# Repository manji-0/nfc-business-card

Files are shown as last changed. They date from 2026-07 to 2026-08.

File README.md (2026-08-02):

# NFC Business Card (KiCad → JLCPCB)

Passive NFC PCB business card: **89 × 51 mm**, URL NDEF, rewritable from iPhone.

| Item | Value |
|---|---|
| IC | NXP **NT3H2111W0FHKH** (Type 2 / NTAG I²C plus) |
| LCSC | **C710403** (JLCPCB Extended, SMT) |
| Board | 2-layer, **0.8 mm**, **black** mask, white silk, ENIG |
| Antenna | Right zone ~29 × 45 mm, **5 turns**, 0.25 / 0.30 mm |
| Text zone | Left **50 mm** — name as **ENIG copper**; roles / QR / contacts in silk |
| Components | 7 mm strip between text and antenna (U1 + C1 DNP) |

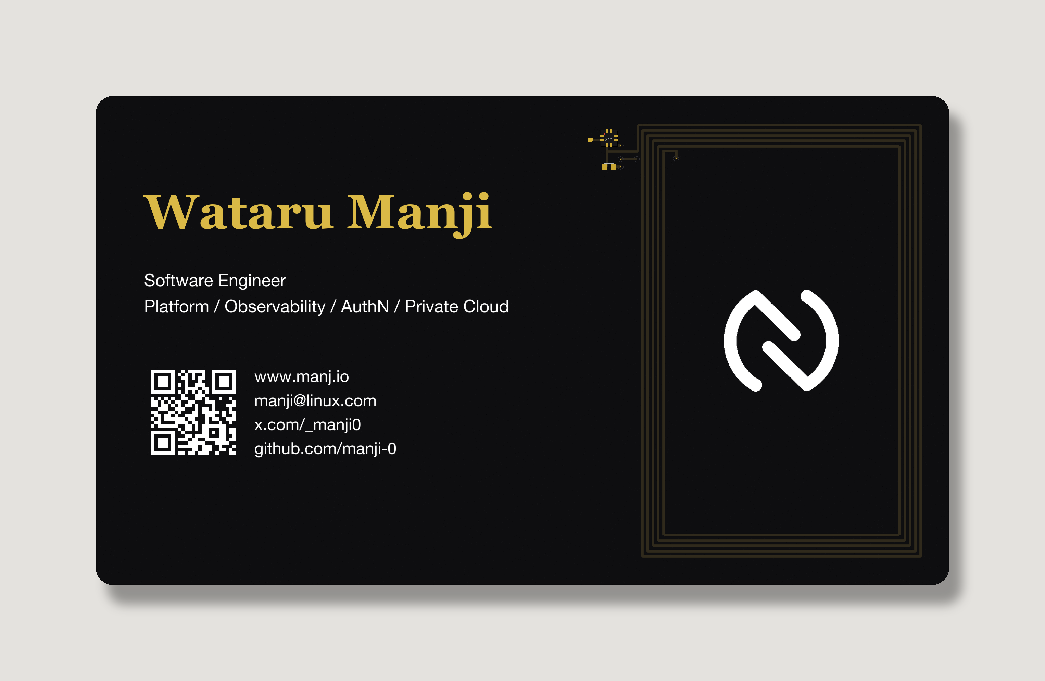
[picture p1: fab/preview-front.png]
Front preview — photoreal mockup


## Repo layout

```
nfc-business-card.kicad_*   KiCad project
lib/                        Symbols & footprints
antenna/                    Design notes + spiral points
fab/                        Gerber zip, BOM, CPL, preview, gerber/
scripts/                    Regenerate project / fab
parts.md                    Locked BOM
```

## Setup (from scratch)

Use **[devbox](https://www.jetify.com/devbox)** + **[uv](https://docs.astral.sh/uv/)** for Python and tooling. KiCad 10+ is installed separately.

```bash
git clone https://github.com/manji-0/nfc-business-card.git
cd nfc-business-card
devbox shell          # installs python, uv, rsvg-convert; runs uv sync
./task export
```

Full guide: **[SETUP.md](SETUP.md)** (fonts, KiCad path, troubleshooting).

## Regenerate design

```bash
./task export          # full pipeline: assets → KiCad → preview → check → fab
./task design          # design only (no Gerber export)
./task list            # show all tasks
```

Individual steps: `./task assets project preview fab` (runs in order).

Open `nfc-business-card.kicad_pro` in KiCad 8+ to edit silk text, tweak antenna, or re-export with **JLCPCB Fabrication Toolkit**.

Photoreal mockup (front + back, regenerated by `./task preview`):

```bash
./task preview
```

Front NFC icon: `assets/nfc-symbol.svg` (from SVG Repo). Check license/terms if you ship commercially.

## Order on JLCPCB

Follow [`fab/ORDER_CHECKLIST.md`](fab/ORDER_CHECKLIST.md).

1. Upload `fab/nfc-business-card-gerbers.zip` (or KiCad Toolkit output).
2. Enable SMT Assembly; upload `fab/bom.csv` + `fab/positions.csv`.
3. Confirm U1 = C710403 and rotation in the preview.
4. First run: **5 boards**.

## Write / rewrite URL (iPhone & Android)

1. Install **NFC Tools** (or NXP TagWriter).
2. Write → Add record → **URL / URI** → your `https://…` page → Write.
3. Tap the card (iPhone: near the top/camera area on modern models).

### Rules for rewritability

- **Do not** use “Lock”, “Make read-only”, or OTP lock. That is permanent.
- Optional: enable **write password only** (PROT = write protect). Reads still open the URL; rewriting needs the password in the same app session.
- After a successful write, lock the phone and tap again to confirm Safari/Chrome opens without an app.

## Design notes

See [`antenna/NOTES.md`](antenna/NOTES.md) and [`parts.md`](parts.md).

- Left **text zone**: name on **F.Cu** (mask opening + ENIG); roles, QR, contacts in silk.
- NFC antenna + chip sit on the **right** (reference-card style).
- If read range is weak, try C1 ≈ **10 pF NP0** first (LCSC **C301961**); then 12/15/18 pF per `parts.md`.

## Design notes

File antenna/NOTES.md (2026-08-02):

# NFC antenna design notes

Board outline: **89.0 × 51.0 mm** (Edge.Cuts).
Chip: **NT3H2111W0FHKH**, Cin = **50 pF** (datasheet).

## Target inductance

Resonance: \( f = 1 / (2\pi\sqrt{L C}) \)

With \( f = 13.56\,\mathrm{MHz} \), \( C = 50\,\mathrm{pF} \):

\[
L = \frac{1}{(2\pi f)^2 C} \approx 2.76\,\mu\mathrm{H}
\]

Design target: **L ≈ 2.0–2.4 µH** (5 turns). With Cin=50 pF alone this is often **~15–16 MHz**;
parasitics and a DNP C1 (**10–22 pF** NP0) pull toward 13.56 MHz on first article.
If range is still poor after C1, consider 6 turns (L≈2.6 µH).

References:

- NXP AN11276 — NFC antenna design
- NXP AN11786 — Antenna design guide for NTAG I²C
- NT3H2111_2211 product data sheet (50 pF input capacitance)

## Geometry used on this card

| Parameter | Value |
|---|---|
| Text zone (left) | **50 mm** — artwork copper-free except ENIG name |
| Component strip | **7 mm** — U1 + C1 at antenna feed |
| Antenna (right) | **~29.5 × 46 mm**, **5 turns**, 0.25 / 0.30 mm |
| Feed | U1/C1 at spiral left edge; LA/LB buses 0.40 mm pitch, 0.18 mm traces |
| Copper under coil | **None** |

Reference-style segregation: electronics at the feed gap, artwork freedom on the left.

Rough L ≈ **1.9 µH** → f_res ≈ **16 MHz** with Cin=50 pF alone. First-article phone tests + C1 decide trim.

## Layout rules

1. Keep ≥ 3 mm clearance from Edge.Cuts to outer turn.
2. Do not place ground **pour** under the spiral. A single thin B.Cu underpass for LB
   (inner end → component strip) is required so F.Cu feed does not cross the outer turn;
   keep it ≤ feed trace width and well clear of any GND island.
3. Place U1 and C1 pads at the feed gap; short LA/LB traces.
4. VSS has a tiny local copper island left of U1 in the component strip — do not flood the antenna area.
5. Center EP of XQFN-8: **no solder paste / no net** (datasheet).
6. The spiral is **netted F.Cu tracks (net LA)**; the antenna footprint is only a
   **net-tie junction** at the coil inner end (`net_tie_pad_groups "1,2"`). The physical
   bridge copper lives in the footprint as two overlapping connect pads: pad 1 (LA)
   spans from the coil end to the take-off, pad 2 (LB) runs from the take-off down to
   via_in. Overlapping pads in a tie group are exempt from the DRC short test, so the
   coil closes to LB with real copper but no cross-net track touch. Do **not** use a
   track to bridge the pads (KiCad 10 DRC reports an LA/LB short) and do not put the
   pads far apart with no overlap (the board stays open). No un-netted copper may
   exist — un-netted spiral `fp_line` copper makes DRC shorting results **UUID-dependent**
   (0/1/2 errors across regenerations). Keep every copper item netted.

## Verification after PCBA

1. Write a short HTTPS URL with NFC Tools.
2. Tap with iPhone (rear camera area) and Android.
3. Note max reliable distance.
4. If < ~5 mm and flaky, try C1 = 10 pF; iterate ±5 pF.

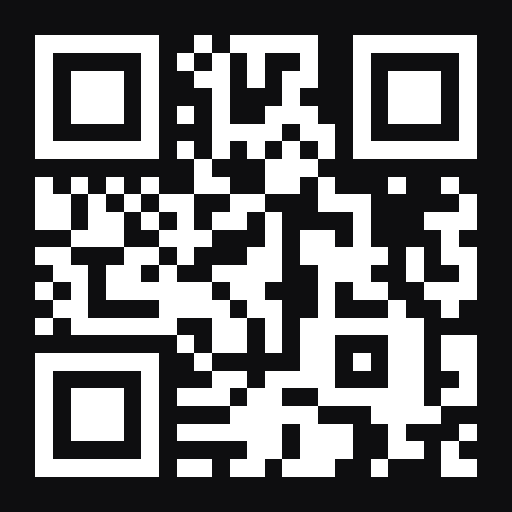
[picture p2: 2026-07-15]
assets/qr-preview.png

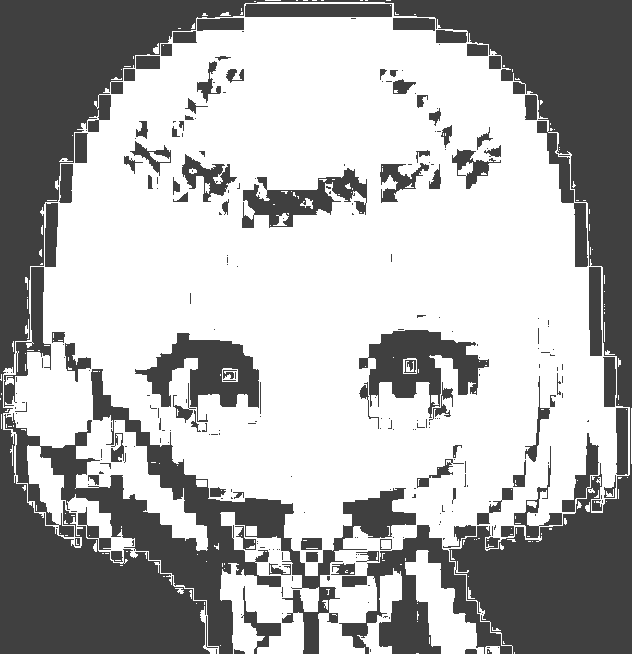
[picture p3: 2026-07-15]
assets/profile-silk.png

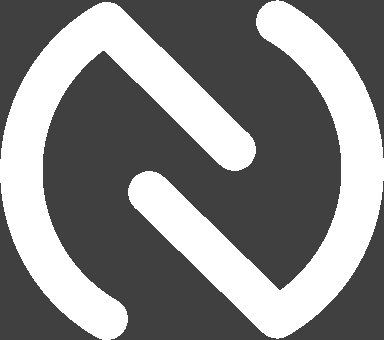
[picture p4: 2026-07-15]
assets/nfc-n-mark-silk.png

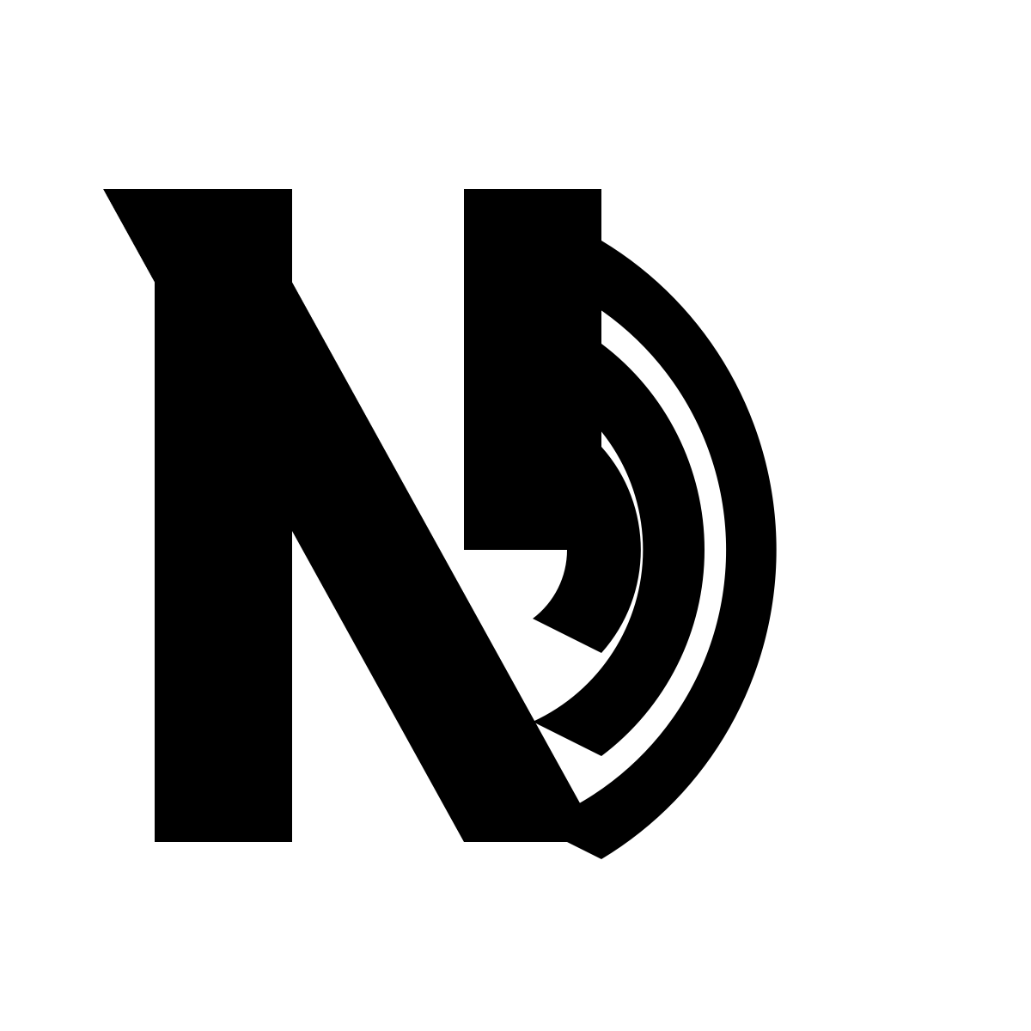
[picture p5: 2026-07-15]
assets/nfc-n-mark.png

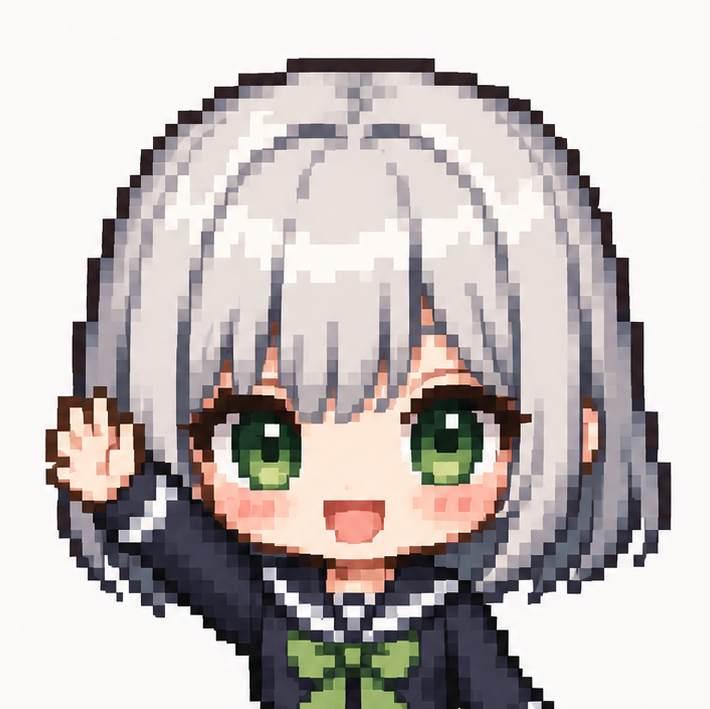
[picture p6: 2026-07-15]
assets/profile.png

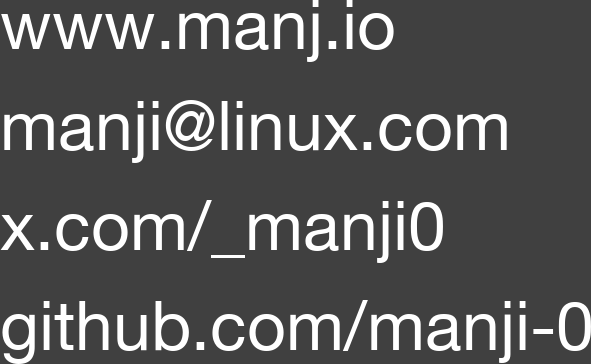
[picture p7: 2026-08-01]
assets/contacts-silk.png

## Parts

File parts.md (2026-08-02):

# Locked BOM — NFC Business Card

Verified 2026-07-14 against LCSC / JLCPCB Parts Library.

## NFC IC (required)

| Field | Value |
|---|---|
| MFR | NXP |
| MPN | **NT3H2111W0FHKH** |
| LCSC / JLCPCB | **C710403** |
| Package | XQFN-8 (1.6 × 1.6 mm), SOT902-3 |
| Type | NFC Forum **Type 2** Tag (NTAG I²C plus, 1 kB) |
| Cin | 50 pF |
| Assembly | JLCPCB SMT (Extended), Economic & Standard |
| LCSC stock (check) | ~10,000+ at lock time |

### Why this part

- Type 2 NDEF → iPhone background URL open works well
- Rewritable from NFC Tools / Core NFC (do not OTP-lock)
- Real SMT package (not wafer / MOA8)
- In stock and listed for JLCPCB assembly

### Pin use (NFC-only business card)

| Pin | Symbol | Connection |
|-----|---|---|
| 1 | LA | Antenna |
| 2 | VSS | Local GND island left of U1 (component strip only; no copper under antenna) |
| 3 | SCL | NC (test pad optional) |
| 4 | FD | NC (test pad optional) |
| 5 | SDA | NC (test pad optional) |
| 6 | VCC | NC (passive RF-powered) |
| 7 | VOUT | NC |
| 8 | LB | Antenna |
| EP | center | **Do not solder** (per datasheet) |

## Tuning capacitor (DNP — pads only)

| Field | Value |
|---|---|
| Ref | C1 |
| Footprint | C_0402_1005Metric |
| Default | **Do Not Place** |
| Candidate if needed | **10–18 pF** NP0/C0G 0402 only (never X7R). See table below. |
| Notes | Parallel across LA–LB. With L≈1.9 µH, Cin=50 pF alone is ~16 MHz; C1 pulls toward 13.56–14.5 MHz. Populate only after first-article phone tests. Run `scripts/tune_antenna.py` for estimates. |

### C1 LCSC parts (verified 2026-08-02)

NP0/C0G **only** — X7R capacitance drifts with voltage/temperature and will not tune reliably at 13.56 MHz.

| Nominal | LCSC | MPN | f_res est. (5T, +3 pF parasitic) | Role |
|---|---|-----|---|---|
| **10 pF** | **C301961** | Walsin 0402N100J500CT | **14.6 MHz** | **Primary** — AN11276 single-tag band (~14.5 MHz) |
| 12 pF | C106201 | YAGEO CC0402JRNPO9BN120 | 14.4 MHz | First SMT populate alternative |
| 15 pF | C106997 | YAGEO CC0402JRNPO9BN150 | 14.0 MHz | If reads still “high” with 10 pF |
| 18 pF | C106202 | YAGEO CC0402JRNPO9BN180 | 13.7 MHz | Toward ISO 13.56 MHz center |
| 22 pF | C1555 | FH 0402CG220J500NT (C0G) | 13.4 MHz | Only if still undertuned after 18 pF |

**BOM default (when populated):** C301961 (10 pF NP0). **First article:** leave DNP; hand-solder 10 pF if range is short.

> **Obsolete/wrong IDs (do not use):** C158992 (681 Ω resistor), C1525 (100 nF X7R), C1528 (160 pF X7R).

## NC pin terminators (DNP — B.Cu pads only)

| Field | Value |
|---|---|
| Ref | R2–R6 |
| Footprint | R_0402_1005Metric (**B.Cu**) |
| Value | **100 kΩ** → VSS (SCL, SDA, FD, VCC, VOUT) |
| MPN | **RC0402FR-07100KL** (YAGEO) |
| LCSC | **C60491** (100 kΩ 0402 ±1%, 62.5 mW) |
| Verified | 2026-08-02 against JLCPCB / LCSC |
| Default | **Do Not Place** |
| Notes | Weak pull-down defines floating NC pins; no RF tuning impact. Populate if field reliability needs margin. |

> **Obsolete/wrong ID (do not use):** C25744 — Uni-Royal 0402WGF1002TCE is **10 kΩ**, not 100 kΩ.

## Alternates (if C710403 unavailable at order time)

1. **ST25TN01K-AFH5** — LCSC C3303589 — Type 2, UFDFN-5 (low stock historically)
2. **ST25TA02K-DC6C5** — LCSC C2654880 — Type 4, UFDFPN-8 (recheck stock)

Do **not** switch to ST25DV / ISO15693 for this card if iPhone tap-to-Safari is required.

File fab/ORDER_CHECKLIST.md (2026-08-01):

# JLCPCB order checklist

## PCB

- Layers: 2
- Dimensions: 89 × 51 mm
- Thickness: **0.8 mm**
- Surface finish: **ENIG**
- Solder mask: **Black**
- Silkscreen: **White**
- Layout: left text zone (ENIG name on F.Cu), right NFC antenna + chip at feed
- Upload **`fab/nfc-business-card-gerbers.zip`** (generated by `./task export` or `./task fab`)
- ENIG name is on **F.Cu** + **F.Mask** opening (not a separate layer)

## SMT Assembly

- Qty: start with **5**
- Side: Top

### Variant A — C1 DNP (hand-tune after test)

- BOM: `fab/bom.csv` (U1 = C710403)
- CPL: `fab/positions.csv`

### Variant B — C1 populated (10 pF NP0, recommended first tuned build)

- BOM: `fab/bom-c1.csv` (U1 = C710403, **C1 = C301961** Walsin 10 pF NP0)
- CPL: `fab/positions-c1.csv` (U1 + C1, F.Cu top)
- C1 value targets ~14.6 MHz resonance (see `scripts/tune_antenna.py`)

CPL uses KiCad pos export (**Mid Y negative**, matches Gerber top-origin).

## Directory layout

```
fab/
  nfc-business-card-gerbers.zip   ← upload to JLCPCB
  bom.csv / positions.csv         ← C1 DNP assembly
  bom-c1.csv / positions-c1.csv   ← C1 populated assembly
  preview.png / preview-front.png
  gerber/                         ← full KiCad export (reference)
```

## Regenerate fab outputs

```bash
./task fab
# or full pipeline:
./task export
```

Requires KiCad 10+ (`kicad-cli` on PATH or macOS app bundle). See [SETUP.md](../SETUP.md).

## JLCPCB options

- Copper: 1 oz (default)
- Board outline tolerance: **Precision** (±0.1 mm) recommended for card size
- Run online DFM before checkout

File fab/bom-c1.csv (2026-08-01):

Designator | Footprint | Quantity | Value | LCSC Part #
U1 | XQFN-8_1.6x1.6mm_P0.4mm_NT3H2111 | 1 | NT3H2111W0FHKH | C710403
C1 | C_0402_1005Metric | 1 | 10pF NP0 | C301961

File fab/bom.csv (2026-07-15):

Designator | Footprint | Quantity | Value | LCSC Part #
U1 | XQFN-8_1.6x1.6mm_P0.4mm_NT3H2111 | 1 | NT3H2111W0FHKH | C710403

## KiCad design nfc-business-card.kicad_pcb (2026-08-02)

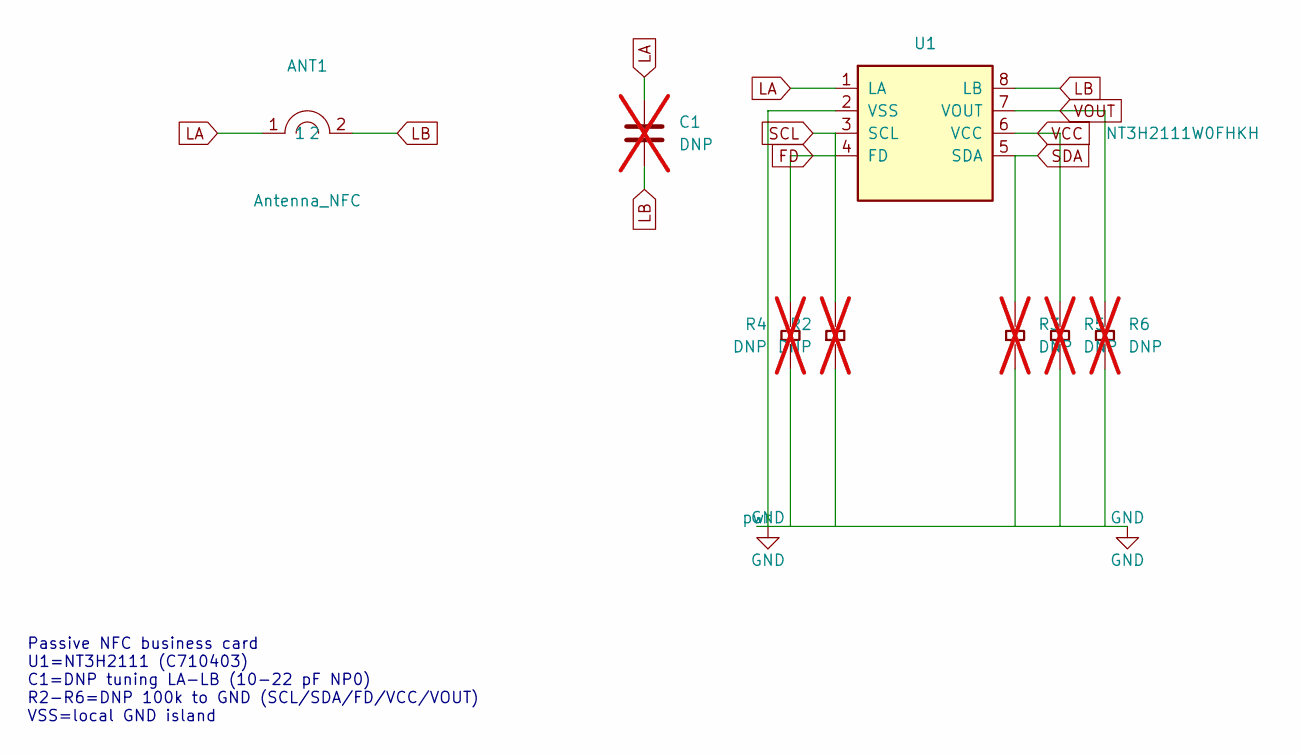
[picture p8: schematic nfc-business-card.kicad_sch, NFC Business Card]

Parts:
ANT1: Antenna_NFC; Antenna_Spiral_29x45_5T
C1: DNP; C_0402_1005Metric; LCSC Part # C301961; not fitted
R2, R3, R4, R5, R6: DNP; R_0402_1005Metric; LCSC Part # C60491; not fitted
U1: NT3H2111W0FHKH; XQFN-8_1.6x1.6mm_P0.4mm_NT3H2111; LCSC Part # C710403

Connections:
FD: R4.1, U1.4 (FD)
GND: R2.2, R3.2, R4.2, R5.2, R6.2, U1.2 (VSS); also elsewhere on the board
LA: ANT1.1, C1.1, U1.1 (LA)
LB: ANT1.2, C1.2, U1.8 (LB)
SCL: R2.1, U1.3 (SCL)
SDA: R3.1, U1.5 (SDA)
VCC: R5.1, U1.6 (VCC)
VOUT: R6.1, U1.7 (VOUT)

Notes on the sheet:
Passive NFC business card U1=NT3H2111 (C710403) C1=DNP tuning LA-LB (10-22 pF NP0) R2-R6=DNP 100k to GND (SCL/SDA/FD/VCC/VOUT) VSS=local GND island

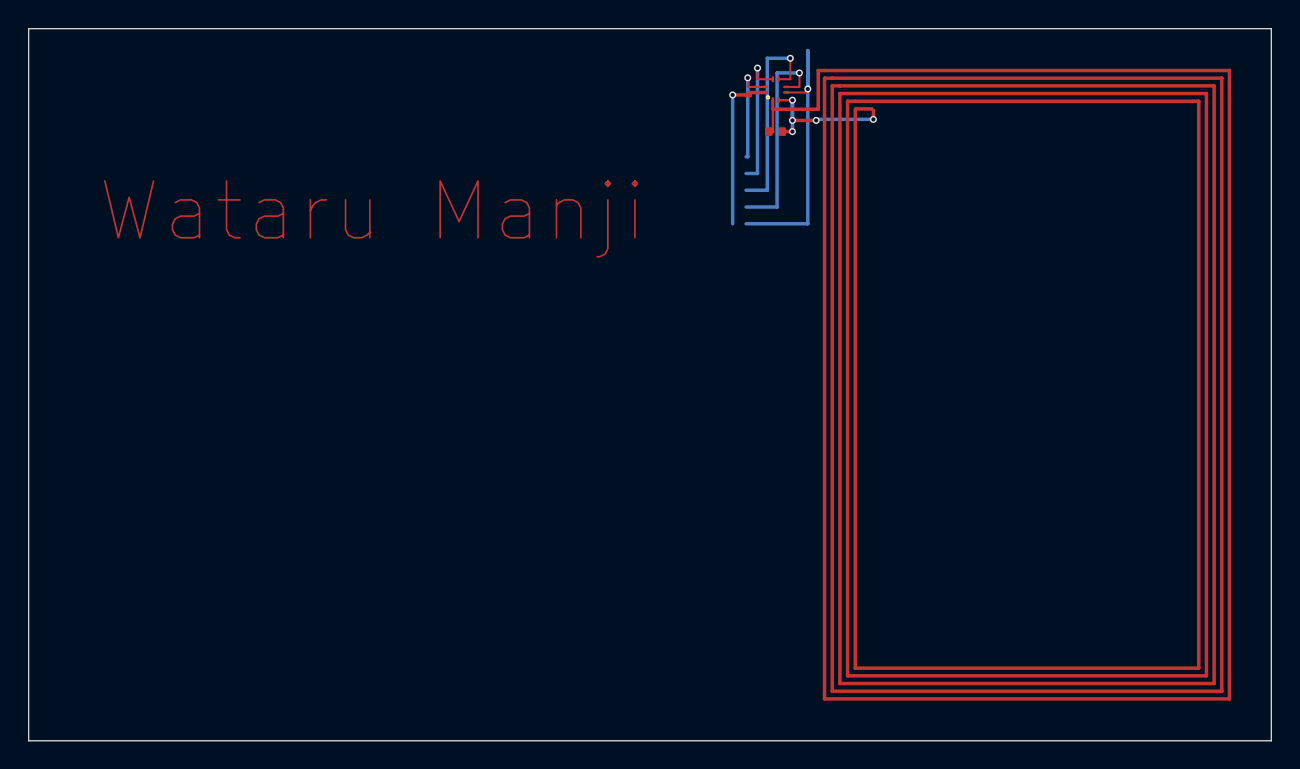
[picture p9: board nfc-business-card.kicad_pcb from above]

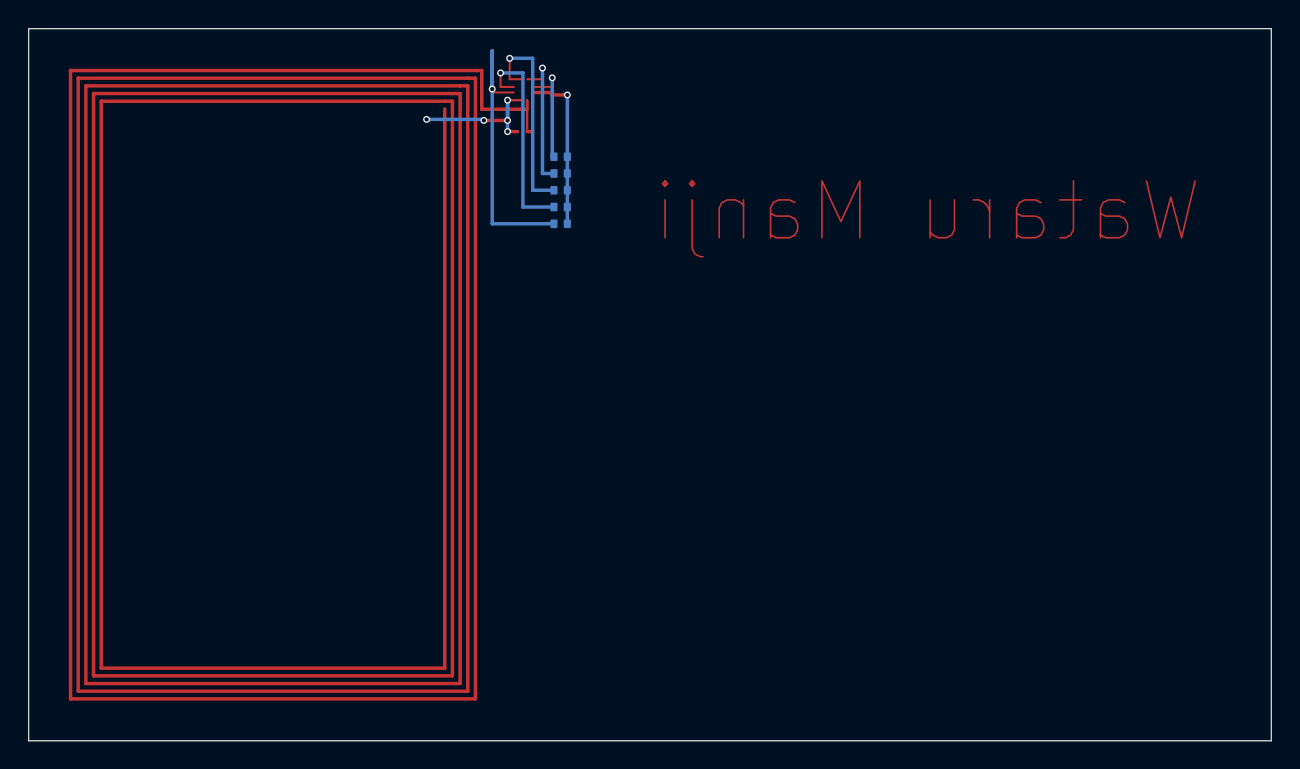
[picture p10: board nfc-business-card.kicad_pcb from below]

Board: 2 copper layers, 89.0 x 51.0 mm, 9 parts (5 on the bottom side), 8 nets.

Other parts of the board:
GND1: GND; GND_Island

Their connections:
GND: GND1.1; also elsewhere on the board

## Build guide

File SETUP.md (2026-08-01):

# セットアップガイド（devbox + uv）

このリポジトリを **1 から** 動かす手順です。Python 依存は **uv**、システムツールは **devbox** で揃えます。KiCad は別途インストールが必要です。

## 前提

| ツール | 用途 |
|---|---|
| [devbox](https://www.jetify.com/devbox) | Python 3.12 / uv / rsvg-convert を隔離インストール |
| [uv](https://docs.astral.sh/uv/) | Python 仮想環境と pip 依存（Pillow, qrcode） |
| **KiCad 10+** | PCB 編集・Gerber 出力・ENIG 名の TTF ベイク |

macOS では KiCad を [公式サイト](https://www.kicad.org/download/) から入れるのが確実です（devbox の `kicad` パッケージは環境によっては入らないことがあります）。

## 1. リポジトリを取得

```bash
git clone https://github.com/manji-0/nfc-business-card.git
cd nfc-business-card
```

## 2. devbox を入れる（未導入の場合）

```bash
curl -fsSL https://get.jetify.com/devbox | bash
```

または [devbox インストール手順](https://www.jetify.com/devbox/docs/installing_devbox/) を参照。

## 3. 開発シェルを起動

```bash
devbox shell
```

初回は Nix パッケージのダウンロードと `uv sync` が走り、`.venv/` が作られます。

シェル内で確認:

```bash
python --version    # 3.12.x
uv --version
rsvg-convert --version
```

## 4. KiCad をインストール

### macOS

1. KiCad 10 を `/Applications/KiCad/` にインストール
2. `devbox shell` / `devbox run` は `scripts/devbox_kicad_path.sh` で App 内 CLI を PATH に載せ、`KICAD_CLI` / `KICAD_PYTHON` / `KICAD_SITE` を自動設定する
3. 確認:

```bash
devbox run -- kicad-cli version
# または
/Applications/KiCad/KiCad.app/Contents/MacOS/kicad-cli version
```

### Linux / カスタムパス

`kicad-cli` が PATH にあるか、環境変数で指定:

```bash
export KICAD_CLI=/path/to/kicad-cli
export KICAD_PYTHON=/path/to/kicad-python   # pcbnew 用（任意）
export KICAD_SITE=/path/to/kicad/site-packages
```

手動で上書きした場合は自動検出より優先される。

## 5. フォント（シルク・ENIG 名）

レイアウトは **Georgia Bold**（氏名）と **Arial**（シルク）を使います。

- **macOS**: システムフォントをそのまま利用（追加不要）
- **Linux**: `fonts-liberation` 等を入れ、必要なら `scripts/layout_metrics.py` / `text_silk.py` のフォントパスを変更

## 6. パイプラインを実行

devbox シェル内:

```bash
./task list
./task design          # アセット → KiCad → プレビュー → チェック
./task export          # 上記 + Gerber zip（KiCad CLI 必須）
```

devbox のショートカット:

```bash
devbox run task
devbox run design
devbox run export
```

## 7. 成果物

| 出力 | パス |
|---|---|
| KiCad プロジェクト | `nfc-business-card.kicad_pro` |
| プレビュー画像 | `fab/preview.png` |
| JLC 用 Gerber zip | `fab/nfc-business-card-gerbers.zip` |
| BOM / CPL | `fab/bom.csv`, `fab/positions.csv` (C1 DNP); **`fab/bom-c1.csv`**, **`fab/positions-c1.csv`** (C1 = C301961 10 pF) |

## トラブルシュート

### `kicad-cli not found`

KiCad をインストールするか `KICAD_CLI` を設定してから `./task fab` を再実行。

### `Georgia Bold` / `Arial` not found

macOS 以外ではフォントパスを確認。`./task design` の前半（PNG 生成）は通っても `generate_kicad_project` の ENIG ベイクで警告が出る場合は KiCad ストロークフォントにフォールバックします。

### `rsvg-convert not found`

`devbox shell` 内で実行しているか確認。devbox の `librsvg` パッケージが `rsvg-convert` を提供します。

### uv / .venv を手動で更新

```bash
uv sync
uv add package-name   # 依存を増やす場合
```

## 最小コマンドまとめ

```bash
git clone https://github.com/manji-0/nfc-business-card.git
cd nfc-business-card
devbox shell
# KiCad 10 をインストール（macOS）
./task export
```

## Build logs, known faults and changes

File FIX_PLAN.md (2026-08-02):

# NFC Business Card PCB Fix Plan

この計画は、短絡、クリアランス違反、部品番号不一致を修正し、修正途中の生成物や未コミット作業を失わないための工程を定義する。

## Verdict

<!-- constrained-by ./AGENTS.md -->

現行出力は発注不可である。2026-08-02 の KiCad 10.0.4 検査では、ERC は通過したが PCB DRC は失敗している。

| 検査 | 現状 | 完了条件 |
|---|---|---|
| KiCad DRC error | 27件 | 0件 |
| KiCad DRC warning | 12件 | 意図したものを除き0件 |
| ERC error | 0件 | 0件 |
| schematic parity | 0件 | 0件 |
| unconnected items | 0件 | 0件 |
| 軽量レイアウト検査 | 通過。ただし不十分 | 強化後も通過 |

## Detected Problems

### Cross-Net Shorting

同一層の異なるネットの配線中心線が交差している。KiCad では `tracks_crossing` として報告されているが、製造上は短絡として扱う。

| ネット | 交差位置 | PCB上の該当配線 |
|---|---|---|
| LA / VOUT | 約 `(54.80, 5.775)` | LA 水平配線と VOUT 垂直配線 |
| GND / VOUT | 約 `(52.25, 4.575)` | GND 水平配線と VOUT 垂直配線 |
| VOUT / GND | 約 `(51.55, 8.90)` | VOUT 水平配線と GND 垂直配線 |

### Clearance

- 要求設計値は 0.20 mm。
- DRCの実測値は 0.025 mm から 0.185 mm。
- 23件すべてが設計値未満。
- 5件は JLC の下限 0.127 mm 未満。
- R3 の SDA パッドと SCL ビアの穴クリアランスは 0.2436 mm で、要求 0.25 mm に届かない。
- LA/LB バスの実効間隔は 0.15 mm で、JLC下限は満たすが設計目標 0.20 mm 未満である。

### Component Identity

<!-- constrained-by ./parts.md -->

- U1 `NT3H2111W0FHKH / C710403` は対象部品と一致する。
- C1 `C301961` は 10 pF、NP0、0402 で対象部品と一致する。
- R2-R6 は設計値が 100 kOhm だが、現在の `C25744` は LCSC上で 10 kOhm 0402 ±1% である。
- R2-R6 はデフォルトDNPのため現行組立BOMには出ないが、オプション実装手順としては不正確である。

## Fixed Design Decisions

<!-- constrained-by ./antenna/NOTES.md -->

- アンテナは 5ターン、トレース 0.25 mm、ターン間ギャップ 0.30 mm、外形約29 x 45 mmを維持する。
- U1 は XQFN-8 1.6 x 1.6 mm、EPは実装しない。
- アンテナ螺旋は net付き F.Cu の LA トラックとし、内側終端は `net_tie_pad_groups "1,2"` の重なりパッドでLBへ接続する。
- no-net の螺旋銅、LA/LBを橋渡しする通常トラック、アンテナ下のGND銅箔は追加しない。
- C1 はDNPを既定とし、初回チューニング用の10 pF NP0候補を維持する。
- R2-R6 はDNPを既定とし、実装する場合だけ検証済み100 kOhm 0402 ±1%部品を指定する。
- `README.md` の6ターン記載は、生成元を変更せず、最後に現行の設計目標へ同期する。

## Worktree Preservation

### Step 0: Freeze the Dirty Worktree

現在の作業ツリーには、PCB、回路図、フットプリント、Gerber、プレビュー、スクリプトの未コミット変更がある。これらを無断で破棄しない。

実施内容:

- `git status --short` を保存する。
- `git diff --stat` と `git diff -- scripts/ nfc-business-card.kicad_pcb nfc-business-card.kicad_pro nfc-business-card.kicad_sch` を確認する。
- 既存変更が今回の修正対象か、別作業かを分類する。
- `.pi/`、一時DRCレポート、実験ファイルを修正対象のコミットから除外する。
- 意図不明の既存変更は、削除・reset・checkoutせず、そのファイルを今回のコミット対象から外す。
- 生成コマンドを実行する前に、上書き対象を確認する。特に `./task design` と `./task export` は生成物を上書きする。

保全ゲート:

- [ ] 既存の変更一覧を作業ログに残した。
- [ ] 今回変更するファイル一覧を確定した。
- [ ] 意図不明の変更をコミットに混ぜない方針を確認した。

コミット:

- 現在の作業ツリーを無断でbaselineコミットしない。
- 既存変更がすべて今回の設計変更であることを確認できた場合だけ、別途 `chore: capture PCB validation baseline` を作成する。

## Validation First

### Step 1: Add Component Invariant Checks

目的は、配線修正と部品修正を同時に行って原因を混ぜないことにある。

変更対象:

- `scripts/check_layout.py` または専用の部品検査スクリプトに、U1、C1、R2-R6のMPN、LCSC ID、値、パッケージ、DNP状態の検査を追加する。
- 100 kOhm指定とLCSC IDの不一致を自動的にエラーにする。
- C1のDNP版と10 pF版がそれぞれ正しいBOM/CPLに出ることを検査する。
- 現行の5ターン、0.25/0.30 mm、3 mmインセットを設計制約として検査する。

検査ゲート:

- [ ] 現行基板で、R2-R6の `C25744` 不一致を再現性のあるエラーとして検出する。
- [ ] U1とC1の正しい部品IDはエラーにならない。
- [ ] 配線問題の失敗と部品問題の失敗を別メッセージで識別できる。

コミット:

- `test: enforce NFC component and antenna invariants`

### Step 2: Add Exhaustive Copper Checks

現行の軽量検査はLA/LBの一部の軸方向重複しか見ておらず、VOUT/GND、VOUT/LAの交差を見逃した。配線修正前に、同じ退行を検出できる検査を先に入れる。

変更対象:

- 同一層の全ネット配線について、交差、重複、最小エッジ間隔を検査する。
- パッド、配線、ビアの銅箔間隔を同一層およびビア貫通範囲で検査する。
- ビア穴とパッド、ビア穴同士のクリアランスを検査する。
- ボード外形、テキストゾーン、アンテナゾーン、コンポーネント帯の境界を検査する。
- net-tie内部のLA/LB重なりだけを明示的な許可リストにする。
- 設計目標 0.20 mm 未満を警告ではなくエラーにする。ただしJLC下限だけを判定する項目は別に残す。
- GNDビアが両層の意図した銅箔へ接続していることを検査する。

検査ゲート:

- [ ] 現行基板で、3箇所の交差を必ず検出する。
- [ ] 0.025 mm、0.095 mm、0.125 mmの既知違反を検出する。
- [ ] 意図したアンテナnet-tieだけは許可される。
- [ ] no-net銅が存在する場合に失敗する。

コミット:

- `test: reject all-net copper crossings and tight clearances`

## Normalize Component Data

### Step 3: Correct the NC Resistor Identity

<!-- constrained-by ./parts.md -->

変更対象:

- `scripts/jlcpcb_limits.py` の `NC_TERM_R_LCSC` を、100 kOhm、0402、±1%として確認したLCSC部品へ変更する。
- `parts.md` のLCSC ID、メーカー型番、抵抗値、定格、検証日を同じ部品に揃える。
- `scripts/generate_kicad_project.py` の生成メタデータは定数から読む状態を維持し、個別のハードコードを増やさない。
- R2-R6のDNP属性、B.Cu配置、SCL/SDA/FD/VCC/VOUTからGNDへの接続意図を維持する。

検査ゲート:

- [ ] 部品検査が通過する。
- [ ] 生成前のソースに100 kOhmとLCSC IDの矛盾がない。
- [ ] 現行PCBをまだ再生成せず、配線修正と混ぜない。

コミット:

- `fix: correct NC terminator component identity`

## Repair Routing in Stages

### Step 4: Build Pure Geometry Routes

<!-- constrained-by ./AGENTS.md -->

配線座標をPCBファイルへ直接編集せず、`scripts/generate_kicad_project.py` の生成元で修正する。

設計手順:

- `nfc_layout()` が返すアンテナ、U1、C1の座標を固定条件として扱う。
- `feed_routes()` のLA/LB RF経路を、既に成立しているアンテナnet-tieとLB B.Cuアンダーパスを壊さない範囲で再配置する。
- `nc_terminator_routes()` の5本のNC経路を、ネットごとの予約チャネルに分ける。
- VOUTの長いF.Cu配線を廃止し、LA、GND、U1パッド、SCLビアを横切らない層遷移を設計する。
- GNDトランクとVOUTトランクは、同一層で交差しないようにする。
- U1直近のF.Cuスタブは、対象パッド以外のU1パッド、他ネットのビア、他ネット配線から0.20 mm以上離す。
- NC信号のB.Cu行配線は、隣接行のパッドとビアを含めて0.20 mm以上離す。
- すべてのNC経路をコンポーネント帯内に収め、アンテナ左辺のkeep-outへ入れない。
- GND遷移は、B.Cuトランクの実配線終端とビア中心を一致させる。未接続の冗長ビアは削除する。

検査ゲート:

- [ ] まず純粋なルートデータを出力し、同一層の全交差が0件である。
- [ ] 全パッド、配線、ビアの最小銅箔間隔が0.20 mm以上である。
- [ ] ビア穴クリアランスが0.25 mm以上である。
- [ ] 既知のLA/VOUT、GND/VOUT、VOUT/GNDの交差が消えている。

コミット:

- `fix: reroute component strip without cross-net tracks`

### Step 5: Pass KiCad DRC on Generated PCB

変更対象:

- `./task design` を実行して、スクリプトからPCB、回路図、フットプリント、プレビューを再生成する。
- `./task check` を実行し、KiCad 10.0.4でERC、DRC、schematic parity、unconnected itemsを検査する。
- DRCのerrorだけでなく、warningを全件確認する。
- `via_dangling`、`lib_footprint_mismatch`、背面フィールドの警告を個別に解消または意図を記録する。

検査ゲート:

- [ ] `./task design` が終了コード0で完了する。
- [ ] DRC errorが0件である。
- [ ] DRC warningが0件、または発注前に許可した理由がある。
- [ ] ERC error、parity、unconnected itemsがすべて0件である。
- [ ] `fab/kicad-drc.json` の生成日時が今回の実行時刻になっている。

コミット:

- 配線修正と同じコミットに生成物を混ぜず、検査が通った後に次の同期コミットへ進む。

## Sync Outputs and Documentation

### Step 6: Synchronize Source and Outputs

<!-- constrained-by ./README.md -->

生成物はソース修正が検査を通った後にだけ更新する。

実施内容:

- `./task design` の出力を確認する。
- `./task fab` を実行し、Gerber、ドリル、BOM、CPL、プレビューを更新する。
- `fab/bom.csv` はC1 DNP版、`fab/bom-c1.csv` はC1 C301961版になっていることを確認する。
- `fab/positions.csv` と `fab/positions-c1.csv` にDNP部品が出ていないことを確認する。
- READMEのアンテナ表記を、生成元と `antenna/NOTES.md` の5ターン、0.25/0.30 mmへ揃える。
- `fab/ORDER_CHECKLIST.md` のU1、C1、基板仕様、検査コマンドを現行出力と照合する。
- transientな `*.rpt`、`fab/kicad-drc.json`、`fab/kicad-erc.json`、`.pi/` はコミット対象にしない。ただし既存の追跡状態を確認してから判断する。

検査ゲート:

- [ ] `git diff --check` が通る。
- [ ] GerberのEdge.Cutsが89 x 51 mmである。
- [ ] 基板厚0.8 mm、2層、黒マスク、白シルク、ENIGの出力条件を確認した。
- [ ] F.Cuアンテナ、B.Cuアンダーパス、GND島、ENIG名の位置をプレビューとGerberで確認した。
- [ ] BOM/CPLの部品IDがソース、PCB、CSVで一致する。

コミット:

- `chore: regenerate verified fabrication outputs`

### Step 7: Independent Pre-Order Review

<!-- constrained-by ./fab/ORDER_CHECKLIST.md -->

生成パイプラインとは別に、発注者が以下を確認する。

- [ ] KiCad DRC画面で除外・無視設定を確認した。
- [ ] 3DまたはGerberビューで、短絡経路がないことを確認した。
- [ ] U1のピン1マークとC1の配置方向を確認した。
- [ ] JLCPCBのオンラインDFMを実行した。
- [ ] U1がC710403、C1 DNP版またはC301961版の選択が正しい。
- [ ] R2-R6を注文BOMへ誤って追加していない。

コミット:

- レポートのみの場合はコミットしない。
- 追加修正が出た場合は、該当するStepへ戻り、新しい修正コミットを作成する。

## Commit Policy

各コミットは1つの責務だけを持たせる。生成物の更新を先行させない。

| 順序 | コミット | 主なファイル | 必須ゲート |
|---|---|---|---|
| 1 | `docs: add staged PCB fix plan` | `FIX_PLAN.md` | Markdown構文、依存関係確認 |
| 2 | `test: enforce NFC component and antenna invariants` | 検査スクリプト | 部品・アンテナ制約を検出 |
| 3 | `test: reject all-net copper crossings and tight clearances` | 検査スクリプト | 現行既知違反を検出 |
| 4 | `fix: correct NC terminator component identity` | `parts.md`, `scripts/jlcpcb_limits.py` | 部品検査通過 |
| 5 | `fix: reroute component strip without cross-net tracks` | `scripts/generate_kicad_project.py` | 交差・クリアランス検査通過 |
| 6 | `chore: regenerate verified fabrication outputs` | PCB、回路図、フットプリント、fab成果物 | `./task check`、BOM/CPL照合 |
| 7 | 必要時のみ追加修正 | 最小範囲 | Step 4以降の該当ゲート |

コミット前に必ず以下を実行する。

- `git status --short`
- `git diff --check`
- `git diff --stat`
- ステージしたファイルだけを対象にした `git diff --cached --check`
- コミットメッセージと変更責務の一致確認

禁止事項:

- `git reset --hard`、`git checkout --`、force pushを使わない。
- 未確認の既存変更を削除しない。
- PCBをKiCad上で直接編集して生成元へ反映しない。
- DRC違反を除外設定で隠して合格扱いにしない。
- 生成されたPCBだけを修正し、次回生成で消える変更を残さない。

## Recovery Procedure

各ステップでゲートが失敗した場合は、次のステップへ進まない。

- 失敗したコマンド、生成日時、エラー件数、座標を記録する。
- 直前のコミットと現在の差分を比較する。
- 修正対象を1つの責務に限定する。
- 生成物を手編集せず、生成元を修正して再生成する。
- 既知の違反件数が増えた場合は、原因を切り分けるまでコミットしない。
- 既にコミット済みのステップへ戻す場合はrevertを新しいコミットとして行い、履歴を書き換えない。

## Summary

<!-- derived-from #verdict -->
<!-- derived-from #detected-problems -->
<!-- derived-from #validation-first -->
<!-- derived-from #normalize-component-data -->
<!-- derived-from #repair-routing-in-stages -->
<!-- derived-from #sync-outputs-and-documentation -->

最初に検査を強化し、次に部品情報を正規化し、その後に生成元の配線を直す。最後にKiCadとfab成果物を再生成して独立レビューを通す。この順序により、配線を直している間に部品IDや生成物の古さが混ざることを防ぐ。

## Conclusion

<!-- derived-from #summary -->

この計画の完了条件は、ソース生成、全ネット銅箔検査、KiCad DRC/ERC、BOM/CPL、Gerber、発注チェックリストが同じ部品仕様と座標制約を示すことである。全ゲートが通るまで発注用zipを更新済みとは扱わない。

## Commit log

2026-07-15 Add NFC business card KiCad generator and layout pipeline.
    Unified preview/KiCad silk placement on top-origin coordinates, PNG silk
    for roles/contacts, and ENIG name baking aligned to Pillow metrics.
    [bom.csv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]
2026-07-15 Refactor scripts with kamae-py domain primitives.
    Introduce Result types, branded Mm/PreviewY, InkBounds, Sensitive PII,
    frozen SilkLayout/CardCopy dataclasses, and boundary validation at asset edges.
    [nfc-business-card.kicad_pcb]
2026-07-15 Document design rules and agent workflow in AGENTS.md.
    Capture board zones, visual layout, preview coordinate system, pipeline
    order, kamae-py conventions, and common pitfalls for AI-assisted edits.
2026-07-15 Add task runner, fab export pipeline, and layout polish.
    KiCad CLI Gerber export with PNG silk merge, ./task runner, larger QR,
    and CPL from KiCad pos coordinates for JLCPCB assembly.
    [nfc-business-card-B_Adhesive.gbr, nfc-business-card-B_Courtyard.gbr, nfc-business-card-B_Mask.gbr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]
2026-08-01 Add devbox/uv setup and portable KiCad path detection.
    Standardize onboarding with devbox, uv, and SETUP.md so the pipeline runs without hardcoded macOS KiCad paths.
2026-08-01 Fix LA–FD short and XQFN pad orientation before fab.
    Route LA around U1, correct side-pad long-axis, add a local VSS island,
    and shrink antenna feed pads so DRC no longer reports real copper shorts.
    [nfc-business-card.kicad_pcb, nfc-business-card.kicad_sch]
2026-08-01 Make antenna a net-tie and route LB under the spiral.
    Declare pads 1–2 as a KiCad net-tie with connect lands so spiral copper is
    an intentional LA↔LB bridge, and move the inner-end feed to B.Cu so DRC can
    flag real shorts instead of spiral false positives.
    [nfc-business-card.kicad_pcb]
2026-08-01 Refresh Gerbers after feed and net-tie fixes.
    Re-export JLCPCB zip from the corrected PCB, and sync KiCad path helpers
    so kicad-cli stays discoverable under devbox.
    [nfc-business-card-B_Adhesive.gbr, nfc-business-card-B_Courtyard.gbr, nfc-business-card-B_Cu.gbr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]
2026-08-01 Clean schematic ERC with NC marks and net labels.
    Connect LA/LB on-grid via labels, mark unused pins no-connect, treat VSS as
    passive local ground with PWR_FLAG, and document C1 10–22 pF trim range.
    [nfc-business-card.kicad_pcb, nfc-business-card.kicad_sch]
2026-08-01 Sync footprint library UUIDs after schematic regen.
2026-08-01 fix(antenna): net coil as F.Cu tracks; footprint is now a net-tie junction
    The spiral was un-netted fp_line copper inside the Antenna_Spiral footprint,
    making DRC shorting results UUID-dependent (0/1/2 errors across
    regenerations). Draw the coil as netted F.Cu tracks (net LA) in write_pcb and
    reduce the footprint to a net-tie junction (net_tie_pad_groups "1,2"):
    pad 1 = LA at the coil inner end, pad 2 = LB at the B.Cu underpass take-off.
    kicad-cli DRC is now 0 violations, deterministic across 5 regenerations.
    Also align C1 (DNP 0402) lib/board footprint (exclude_from_bom, DNP F.Fab
    value, LCSC Part # C158992, F.Fab lines) clearing the lib_footprint_mismatch
    warning; convert LA/LB schematic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
    [nfc-business-card-B_Adhesive.gbr, nfc-business-card-B_Courtyard.gbr, nfc-business-card-B_Cu.gbr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]
2026-08-01 feat(stability): NC pull-downs, C1 BOM fix, and tuned assembly exports
    Add DNP R2–R6 (100 kΩ to VSS on B.Cu) for floating NC pins, lock C1 to
    Walsin 10 pF NP0 (C301961), and export bom-c1/positions-c1 for JLC SMT.
    Correct wrong LCSC IDs in parts.md and add tune_antenna.py for C1/turn trim.
    [bom-c1.csv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]
2026-08-01 feat(design): Baskerville/Helvetica typography, larger type scale, centered QR block
    - Font registry scripts/fonts.py: single source of truth (face -> TTF/TTC
    with index) shared by preview, KiCad bake, and layout checks
    - ENIG name: Georgia Bold -> Baskerville SemiBold (cap 5.2 -> 5.5 mm)
    - Silk: Arial -> Helvetica Neue (roles 1.6 -> 1.8 mm, contacts 1.5 -> 1.7 mm)
    - QR + contacts block moved down (center 28.5 -> 33.0 mm): roles->QR gap
    0.05 -> 4.55 mm, left column now centered vs antenna zone
    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
    [nfc-business-card.kicad_pcb, nfc-business-card.kicad_sch]
2026-08-02 feat(design): real-board preview fidelity and Georgia Bold ENIG name
    - LA/LB feeds at 0.25 mm (match antenna) and rendered under-mask in preview
    - Preview draws net-tie pads, tented vias, GND island, B.Cu hints
    - Name font switched to Georgia Bold (em 5.1 mm) via split_font.py
    (unique 'GeorgiaBold' family resolves in KiCad; system-registered)
    - fontconfig config wired into pcbnow bake and kicad-cli fab exports
    - fonttools dep for font splitting
    [nfc-business-card-B_Adhesive.gbr, nfc-business-card-B_Courtyard.gbr, nfc-business-card-B_Cu.gbr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]
2026-08-02 docs: add staged PCB fix plan
2026-08-02 test: enforce NFC component and antenna invariants
2026-08-02 fix: route LB under LA skirt without shorting VOUT
    Keep the westbound VOUT crossing on F.Cu above the LA skirt, and drop
    to B.Cu only in the clearance column between VCC and VOUT. Lower the
    KiCad min track width to the JLC floor so intentional 0.15 mm NC stubs
    pass DRC.
    [nfc-business-card.kicad_pcb, nfc-business-card.kicad_sch]
2026-08-02 chore: regenerate verified fabrication outputs
    Sync Gerbers/drill zip after the DRC-clean routing fix, and align README
    antenna specs with the 5-turn 0.25/0.30 mm design source of truth.
    [nfc-business-card-B_Adhesive.gbr, nfc-business-card-B_Courtyard.gbr, nfc-business-card-B_Cu.gbr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]
2026-08-02 fix: detach LA feed from antenna left-edge short
    Step the LA feed west off the spiral start before rising so it no
    longer T-junctions onto the outer left turn and shorts turn 1. Guard
    the regression in check_layout and refresh fab outputs.
    [nfc-business-card-B_Adhesive.gbr, nfc-business-card-B_Courtyard.gbr, nfc-business-card-B_Cu.gbr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]
2026-08-02 fix: clear schematic parity and stop greenwashing DRC warnings
    Correct eeschema Y mapping for U1–R NC wiring, skip degenerate VOUT
    segments, require CLI checks to fail on unaccepted warnings/parity, and
    only allowlist LA/LB for clearance (not crossings).
    [nfc-business-card-B_Adhesive.gbr, nfc-business-card-B_Courtyard.gbr, nfc-business-card-B_Cu.gbr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]
2026-08-02 refactor: tidy schematic layout with label-joined RF and R bank
    Replace spaghetti NC/RF wiring with ANT–C1–U1 labels, a spaced vertical
    R2–R6 pull-down row, and a segmented GND rail so ERC and parity stay clean.
    [nfc-business-card.kicad_pcb, nfc-business-card.kicad_sch]
2026-08-02 refactor: widen LA/LB bus gap and keep schematic R bank off the U1 body
    - FEED_BUS_W_MM=0.18 (XQFN ROW) on the 0.40 mm-pitch bus columns:
    parallel pair gap 0.15 -> 0.22 mm, still antenna width elsewhere, no
    width step at the XQFN pads
    - schematic R2-R6 columns moved outside the U1 symbol body so no vertical
    or jog crosses the rectangle; net labels on the outward jog/stub
    - second GND symbol (#PWR02) on the rail's right end; title-block date
    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
    [nfc-business-card.kicad_pcb, nfc-business-card.kicad_sch]
2026-08-02 refactor: type NC fan-out table as frozen dataclasses
    NC_FANOUT was dict[str, dict] with heterogeneous keys (stub/via/col/row/
    narrow/bc_via_y). Introduce NcTerminator + NcFanout frozen dataclasses
    (kamae) and switch placements/routes to attribute access. Values unchanged.
2026-08-02 refactor: single source for XQFN-8 pad geometry
    XQFN pad table lived in three places (footprint writer, PCB U1 builder,
    check_layout). Move (x, y, rot, net) table, pad_wh and pad_bbox into
    scripts/xqfn_geometry.py; footprint writer keeps insertion order and the
    PCB builder iterates numerically so regenerated files stay byte-stable.
2026-08-02 refactor: shared antenna spiral + L-model module
    The Wheeler L estimate lived in three places (generator estimate.txt,
    check_layout warning band, tune_antenna) with drifting fill guards.
    Add scripts/antenna_model.py as the single source for rectangular_spiral,
    estimate_l_uh, f_res_mhz, c_needed_pf; generator re-exports rectangular_spiral
    so render_preview/tune_antenna imports keep working.
2026-08-02 refactor: single source for symbol definitions
    write_symbol_lib() and the schematic's embedded lib_symbols duplicated the
    same NT3H2111/Antenna/C/R/GND/PWR_FLAG definitions in two formats that could
    drift apart. Add scripts/symbol_lib.py as the canonical copy (multi-line
    .kicad_sym format); the schematic embed derives from it via a compact-to-one-
    node-per-line transform. Regenerated .kicad_sch is byte-identical; the
    .kicad_sym only changes symbol order (R_0402 before GND/PWR_FLAG, schematic
    embed order) which is semantically neutral — ERC/DRC/parity pass.
2026-08-02 chore: regenerate verified fabrication outputs
    [nfc-business-card-B_Adhesive.gbr, nfc-business-card-B_Courtyard.gbr, nfc-business-card-B_Cu.gbr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]
2026-08-02 refactor: sexpr writer — indentation from nesting, never hand-typed tabs
    Hand-typed '\t' prefixes in every emitter (kicad10.py, kicad_bitmap.py,
    generate_kicad_project.py, symbol_lib.py) are replaced by two abstractions in
    scripts/sexpr.py:
    - SexprDoc: imperative writer; each nesting level = one tab (node()/line()/
    embed()/blank()/raw()). All PCB/schematic/footprint builders use it; helpers
    return relative docs embedded at the caller's depth (fp_pad_connect_roundrect
    drops its indent= param).
    - Sexpr + render_sexpr: declarative tree with per-symbol multiline sets, so the
    .kicad_sym file and the schematic's embedded lib_symbols both derive from one
    definition (the regex compactif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
2026-08-02 docs: document refactored single-source modules in AGENTS.md
    Source-of-truth table gains antenna_model.py / xqfn_geometry.py /
    symbol_lib.py / sexpr.py rows; code-design section describes the sexpr
    abstraction (SexprDoc + Sexpr tree, no hand-typed tabs).
2026-08-04 chore: add fresh DRC/ERC reports, drop stale test-pcb2 reports
